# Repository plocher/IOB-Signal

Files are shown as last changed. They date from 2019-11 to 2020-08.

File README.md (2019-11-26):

# IOB-Signal
## License: CERN Open Hardware Licence v1.2

IOB Interface drives 2x Signal Heads via a RJ45/8 connector.

PNP Ready: IOB Signal interface for my I2C-7311 IO expansion board and a RJ45 SignalHead Adapter board.

  * pin 1: 5vDC
  * pin 2: Head1-A
  * pin 3: Head1-B
  * pin 4: Head2-A
  * pin 5: Head2-B
  * pin 6: GND

Logic - write a total of 4 bits to the desired expander nibble, 2 bits per head:

| Head1 | bit4 | bit3 | bit1 | bit0 | Indication    |
|------ |:----:|:----:|:----:|:----:|:==========    |
|       |  -   |  -   |  0   |  0   | 0b00 = GREEN  |
|------ |----- |----- |----- |----- |-----------    |
|       |  -   |  -   |  0   |  1   | 0b01 = RED    |
|------ |----- |----- |----- |----- |-----------    |
|       |  -   |  -   |  1   |  0   | 0b10 = YELLOW |
|------ |----- |----- |----- |----- |-----------    |
|       |  -   |  -   |  1   |  1   | 0b11 = DARK   |
|------ |----- |----- |----- |----- |-----------    |

| Head2 | bit4 | bit3 | bit1 | bit0 | Indication    |
|------ |:----:|:----:|:----:|:----:|:==========    |
|       |  0   |  0   |  -   |  -   | 0b00 = GREEN  |
|------ |----- |----- |----- |----- |-----------    |
|       |  0   |  1   |  -   |  -   | 0b01 = RED    |
|------ |----- |----- |----- |----- |-----------    |
|       |  1   |  0   |  -   |  -   | 0b10 = YELLOW |
|------ |----- |----- |----- |----- |-----------    |
|       |  1   |  1   |  -   |  -   | 0b11 = DARK   |
|------ |----- |----- |----- |----- |-----------    |

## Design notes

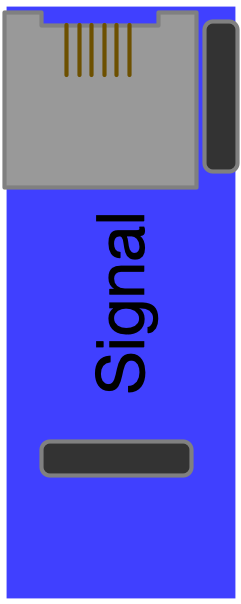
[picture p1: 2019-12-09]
IOB-Signal-Graphic.png

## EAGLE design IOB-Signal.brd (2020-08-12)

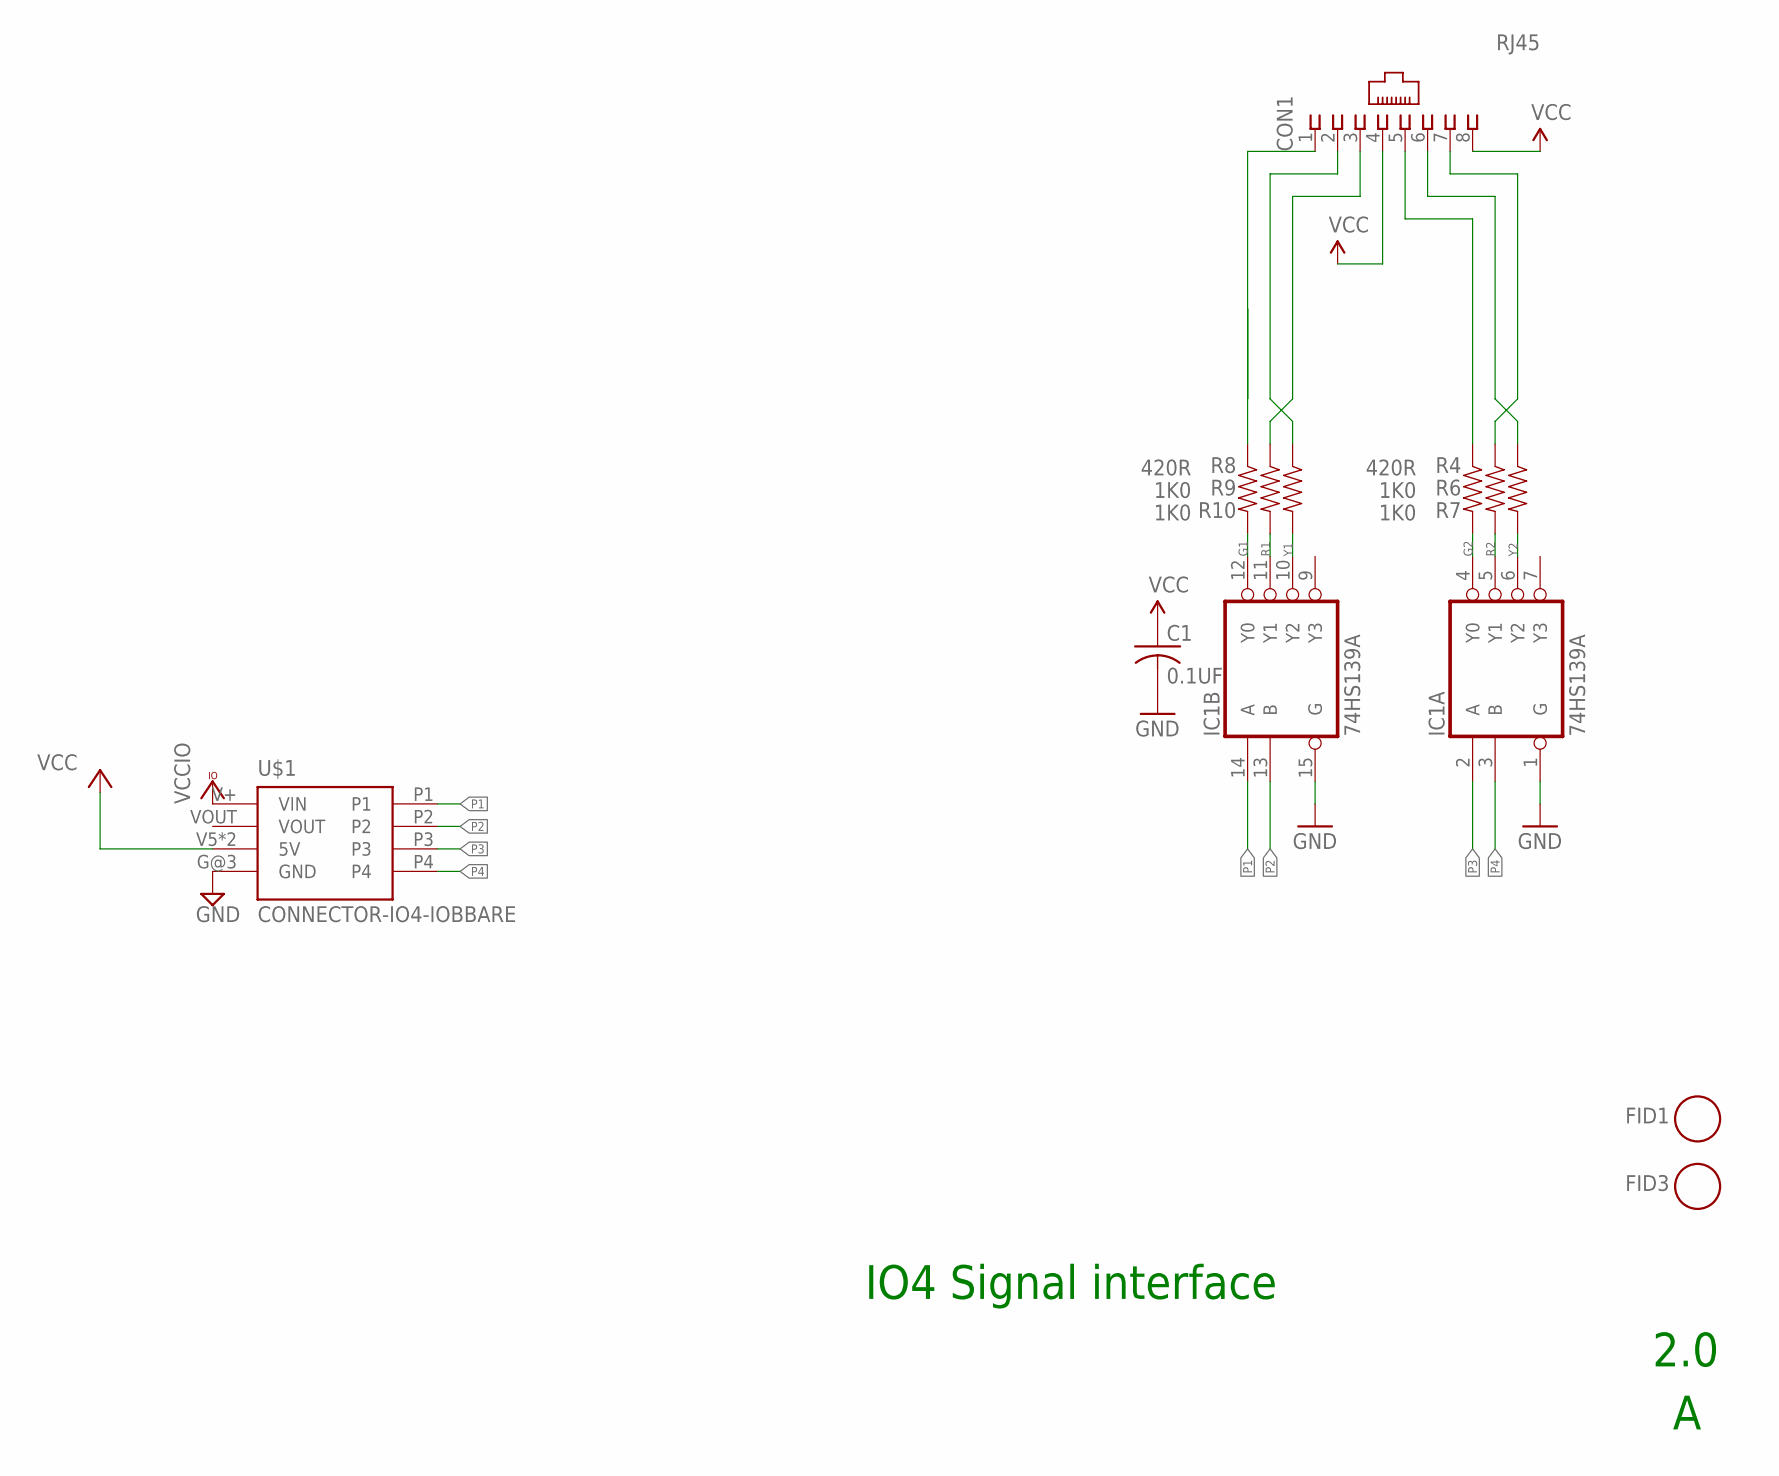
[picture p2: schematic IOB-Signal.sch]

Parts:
C1: 0.1UF; 0805-CAP
CON1: RJ45; RJ45-NO-SHIELD
FID1, FID3: FIDUCIAL; FIDUCIAL_1MM
IC1: 74HS139A; SO16
R4, R8: 420R; 0805-RES
R6, R7, R9, R10: 1K0; 0805-RES
U$1: CONNECTOR-IO4-IOBBARE; IO4-IOB

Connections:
G1: IC1.12 (Y0), R10.2
G1-LED: CON1.1, R10.1
G2: IC1.4 (Y0), R7.2
G2-LED: CON1.5, R7.1
GND: C1.2, IC1.1 (G), IC1.8 (GND), IC1.15 (G), U$1.G@3 (GND)
P1: IC1.14 (A), U$1.P1
P2: IC1.13 (B), U$1.P2
P3: IC1.2 (A), U$1.P3
P4: IC1.3 (B), U$1.P4
R1: IC1.11 (Y1), R9.2
R1-LED: CON1.3, R9.1
R2: IC1.5 (Y1), R6.2
R2-LED: CON1.7, R6.1
VCC: C1.1, CON1.4, CON1.8, IC1.16 (VCC), U$1.V5 (5V), U$1.V5@1 (5V)
VCCIO: U$1.V+ (VIN)
Y1: IC1.10 (Y2), R8.2
Y1-LED: CON1.2, R8.1
Y2: IC1.6 (Y2), R4.2
Y2-LED: CON1.6, R4.1

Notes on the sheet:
IO4 Signal interface
2.0

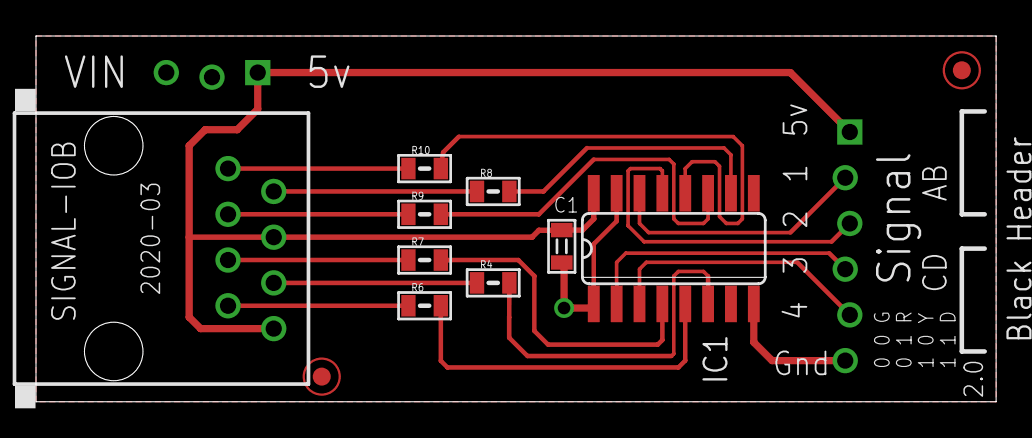
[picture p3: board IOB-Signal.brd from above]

Board: 2 copper layers, 53.3 x 20.3 mm, 12 parts (0 on the bottom side), 18 nets.

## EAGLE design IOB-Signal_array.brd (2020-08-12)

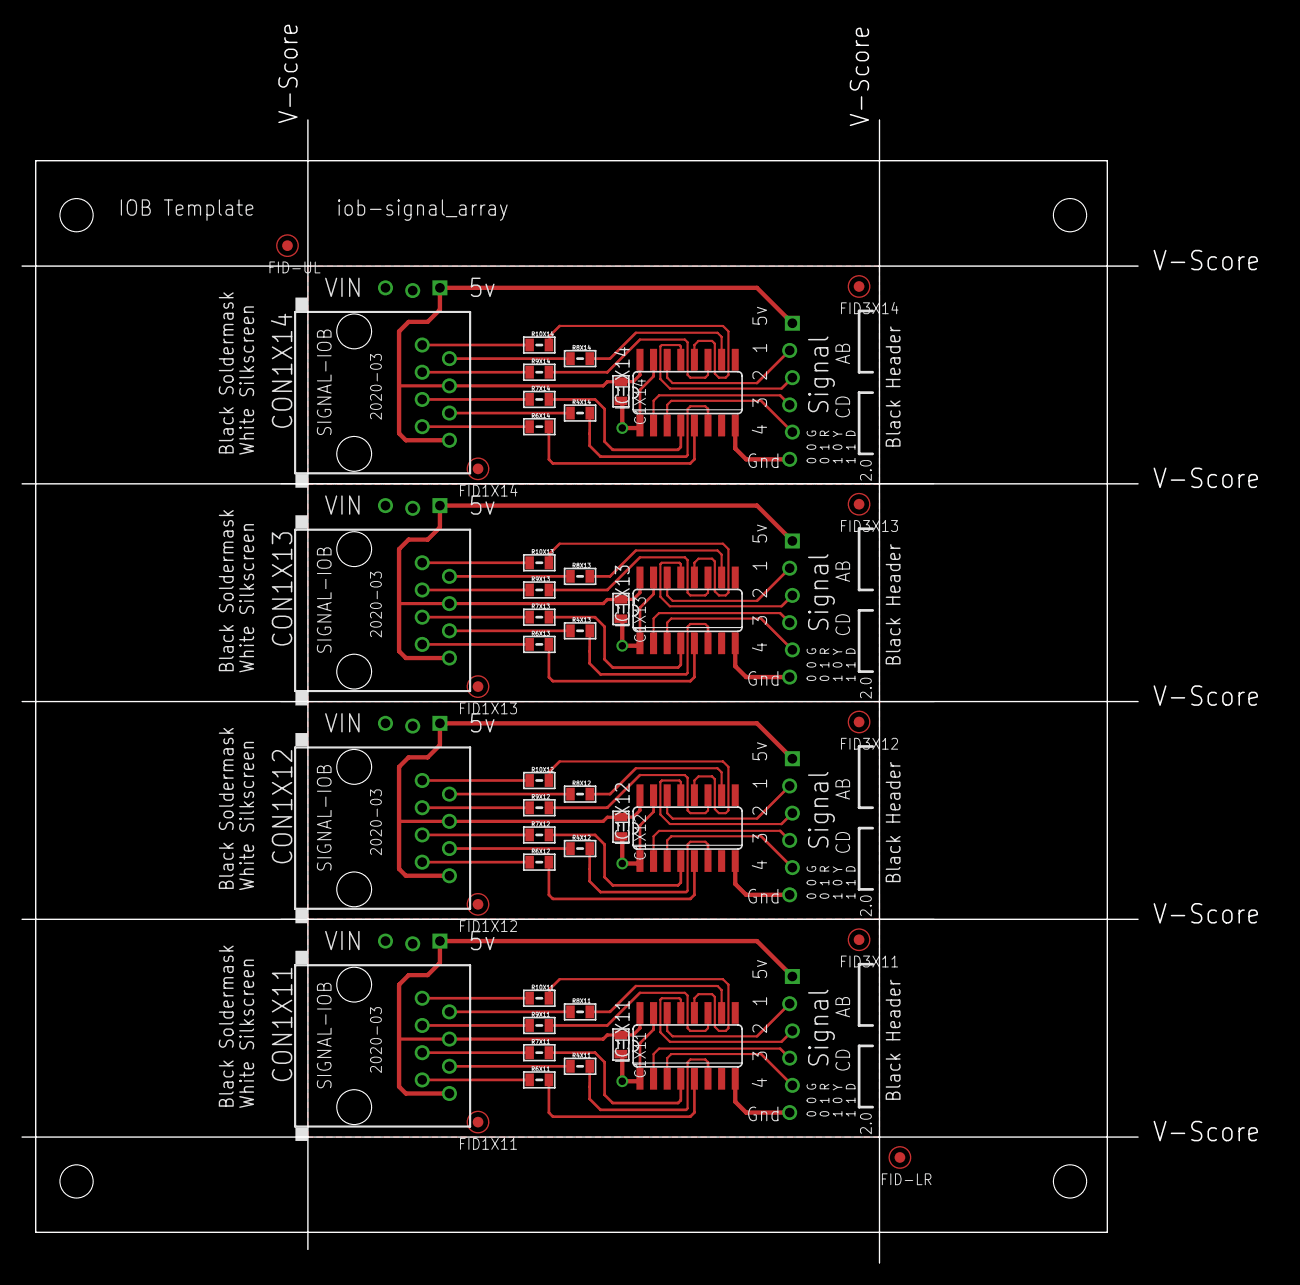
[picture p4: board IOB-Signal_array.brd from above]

Board: 2 copper layers, 104.1 x 106.7 mm, 51 parts (0 on the bottom side), 72 nets.

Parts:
C1X11, C1X12, C1X13, C1X14: 0.1UF; 0805-CAP
CON1X11, CON1X12, CON1X13, CON1X14: RJ45; RJ45-NO-SHIELD
FID1X11, FID1X12, FID1X13, FID1X14, FID3X11, FID3X12, FID3X13, FID3X14: FIDUCIAL; FIDUCIAL_1MM
FID-LR: FIDUCIAL; FIDUCIAL_1MM
FID-UL: FIDUCIAL; FIDUCIAL_1MM
IC1X11, IC1X12, IC1X13, IC1X14: 74HS139A; SO16
R4X11, R4X12, R4X13, R4X14, R8X11, R8X12, R8X13, R8X14: 420R; 0805-RES
R6X11, R6X12, R6X13, R6X14, R7X11, R7X12, R7X13, R7X14, R9X11, R9X12, R9X13, R9X14, R10X11, R10X12, R10X13, R10X14: 1K0; 0805-RES
U$1X1: BOARD-DINRAIL-3.17IN-H4X-IOB
U$1X11, U$1X12, U$1X13, U$1X14: CONNECTOR-IO4-IOBBARE; IO4-IOB

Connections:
G1-LEDX11: CON1X11.1, R10X11.1
G1-LEDX12: CON1X12.1, R10X12.1
G1-LEDX13: CON1X13.1, R10X13.1
G1-LEDX14: CON1X14.1, R10X14.1
G1X11: IC1X11.12, R10X11.2
G1X12: IC1X12.12, R10X12.2
G1X13: IC1X13.12, R10X13.2
G1X14: IC1X14.12, R10X14.2
G2-LEDX11: CON1X11.5, R7X11.1
G2-LEDX12: CON1X12.5, R7X12.1
G2-LEDX13: CON1X13.5, R7X13.1
G2-LEDX14: CON1X14.5, R7X14.1
G2X11: IC1X11.4, R7X11.2
G2X12: IC1X12.4, R7X12.2
G2X13: IC1X13.4, R7X13.2
G2X14: IC1X14.4, R7X14.2
GNDX11: C1X11.2, IC1X11.1, IC1X11.8, IC1X11.15, U$1X11.G@3
GNDX12: C1X12.2, IC1X12.1, IC1X12.8, IC1X12.15, U$1X12.G@3
GNDX13: C1X13.2, IC1X13.1, IC1X13.8, IC1X13.15, U$1X13.G@3
GNDX14: C1X14.2, IC1X14.1, IC1X14.8, IC1X14.15, U$1X14.G@3
P1X11: IC1X11.14, U$1X11.P1
P1X12: IC1X12.14, U$1X12.P1
P1X13: IC1X13.14, U$1X13.P1
P1X14: IC1X14.14, U$1X14.P1
P2X11: IC1X11.13, U$1X11.P2
P2X12: IC1X12.13, U$1X12.P2
P2X13: IC1X13.13, U$1X13.P2
P2X14: IC1X14.13, U$1X14.P2
P3X11: IC1X11.2, U$1X11.P3
P3X12: IC1X12.2, U$1X12.P3
P3X13: IC1X13.2, U$1X13.P3
P3X14: IC1X14.2, U$1X14.P3
P4X11: IC1X11.3, U$1X11.P4
P4X12: IC1X12.3, U$1X12.P4
P4X13: IC1X13.3, U$1X13.P4
P4X14: IC1X14.3, U$1X14.P4
R1-LEDX11: CON1X11.3, R9X11.1
R1-LEDX12: CON1X12.3, R9X12.1
R1-LEDX13: CON1X13.3, R9X13.1
R1-LEDX14: CON1X14.3, R9X14.1
R1X11: IC1X11.11, R9X11.2
R1X12: IC1X12.11, R9X12.2
R1X13: IC1X13.11, R9X13.2
R1X14: IC1X14.11, R9X14.2
R2-LEDX11: CON1X11.7, R6X11.1
R2-LEDX12: CON1X12.7, R6X12.1
R2-LEDX13: CON1X13.7, R6X13.1
R2-LEDX14: CON1X14.7, R6X14.1
R2X11: IC1X11.5, R6X11.2
R2X12: IC1X12.5, R6X12.2
R2X13: IC1X13.5, R6X13.2
R2X14: IC1X14.5, R6X14.2
VCCX11: C1X11.1, CON1X11.4, CON1X11.8, IC1X11.16, U$1X11.V5, U$1X11.V5@1
VCCX12: C1X12.1, CON1X12.4, CON1X12.8, IC1X12.16, U$1X12.V5, U$1X12.V5@1
VCCX13: C1X13.1, CON1X13.4, CON1X13.8, IC1X13.16, U$1X13.V5, U$1X13.V5@1
VCCX14: C1X14.1, CON1X14.4, CON1X14.8, IC1X14.16, U$1X14.V5, U$1X14.V5@1
Y1-LEDX11: CON1X11.2, R8X11.1
Y1-LEDX12: CON1X12.2, R8X12.1
Y1-LEDX13: CON1X13.2, R8X13.1
Y1-LEDX14: CON1X14.2, R8X14.1
Y1X11: IC1X11.10, R8X11.2
Y1X12: IC1X12.10, R8X12.2
Y1X13: IC1X13.10, R8X13.2
Y1X14: IC1X14.10, R8X14.2
Y2-LEDX11: CON1X11.6, R4X11.1
Y2-LEDX12: CON1X12.6, R4X12.1
Y2-LEDX13: CON1X13.6, R4X13.1
Y2-LEDX14: CON1X14.6, R4X14.1
Y2X11: IC1X11.6, R4X11.2
Y2X12: IC1X12.6, R4X12.2
Y2X13: IC1X13.6, R4X13.2
Y2X14: IC1X14.6, R4X14.2

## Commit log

2020-03-06 new IOB format
    [IOB-Signal.brd, IOB-Signal.sch, IOB-Signal_array.brd]
2020-08-09 fixed SPCoast.lbr diode orientation
    [IOB-Signal.brd, IOB-Signal.sch, IOB-Signal_array.brd]
2020-08-09 Added missing values
    [IOB-Signal_array.brd]
2020-08-11 normalized silkscreen layout across IOBs
    [IOB-Signal.brd, IOB-Signal_array.brd]
2020-08-11 bottom silk alignment
    [IOB-Signal.brd, IOB-Signal_array.brd]
2020-08-12 Black soldermask
    [IOB-Signal.brd, IOB-Signal_array.brd]
